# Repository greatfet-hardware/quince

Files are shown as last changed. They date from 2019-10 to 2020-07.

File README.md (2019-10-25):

# Quince
a 2.4 GHz SDR neighbor for GreatFET using 1-bit ADCs

Quince is a GreatFET neighbor that serves as a Software Defined Radio (SDR) receiver for the 2.4 GHz band using a 1-bit sampling technique.  It is intended specifically to enable all-channel Bluetooth monitoring, but it should support additional uses.

Quince features the TLV3502 dual comparator and an RF section based on the AD8347 quadrature demodulator.  Synthesis of a 2.4 GHz Local Oscillator (LO) is provided by ADF4360-0.  The 1-bit quadrature signals are sampled at 80+ Msps by the SGPIO peripheral on [Azalea](https://github.com/greatfet-hardware/azalea).

Channelization and demodulation are done in software on the host computer, but it may be necessary to add an FPGA to Quince in order to achieve real-time simultaneous monitoring of all Bluetooth channels.  The host software will likely be a rewrite of [gr-bluetooth](https://github.com/greatscottgadgets/gr-bluetooth) using [libbtbb](https://github.com/greatscottgadgets/libbtbb) (the core of software for [Ubertooth](https://greatscottgadgets.com/ubertoothone/)).

## Project Status

The first hardware prototype that achieves proof-of-concept has been assembled.  Software work is required before determining what changes are needed in the next hardware revision.

## Viewing or Modifying the Design

Required KiCad dependency:

https://github.com/greatscottgadgets/gsg-kicad-lib

If you are using git, the preferred way to install gsg-kicad-lib is to use the
submodule:

```
git submodule init && git submodule update
```

## Hardware Development Notes

Lower cost comparators that may have sufficient bandwidth:
* TLV3202, comparator, $0.60
* NCS2250, single, $0.20

It might be more cost-effective to use a wireless transmitter or transceiver IC to generate the LO, such as:
* CC2500
* ADF7242 (used on [Lucky Bamboo](https://github.com/greatfet-hardware/luckybamboo))

As an alternative to the comparators (and possibly to the quadrature demodulator as well) we may investigate the use of LVDS input on an FPGA.  This would be the preferred solution if an FPGA ends up on the board anyway for channelization.

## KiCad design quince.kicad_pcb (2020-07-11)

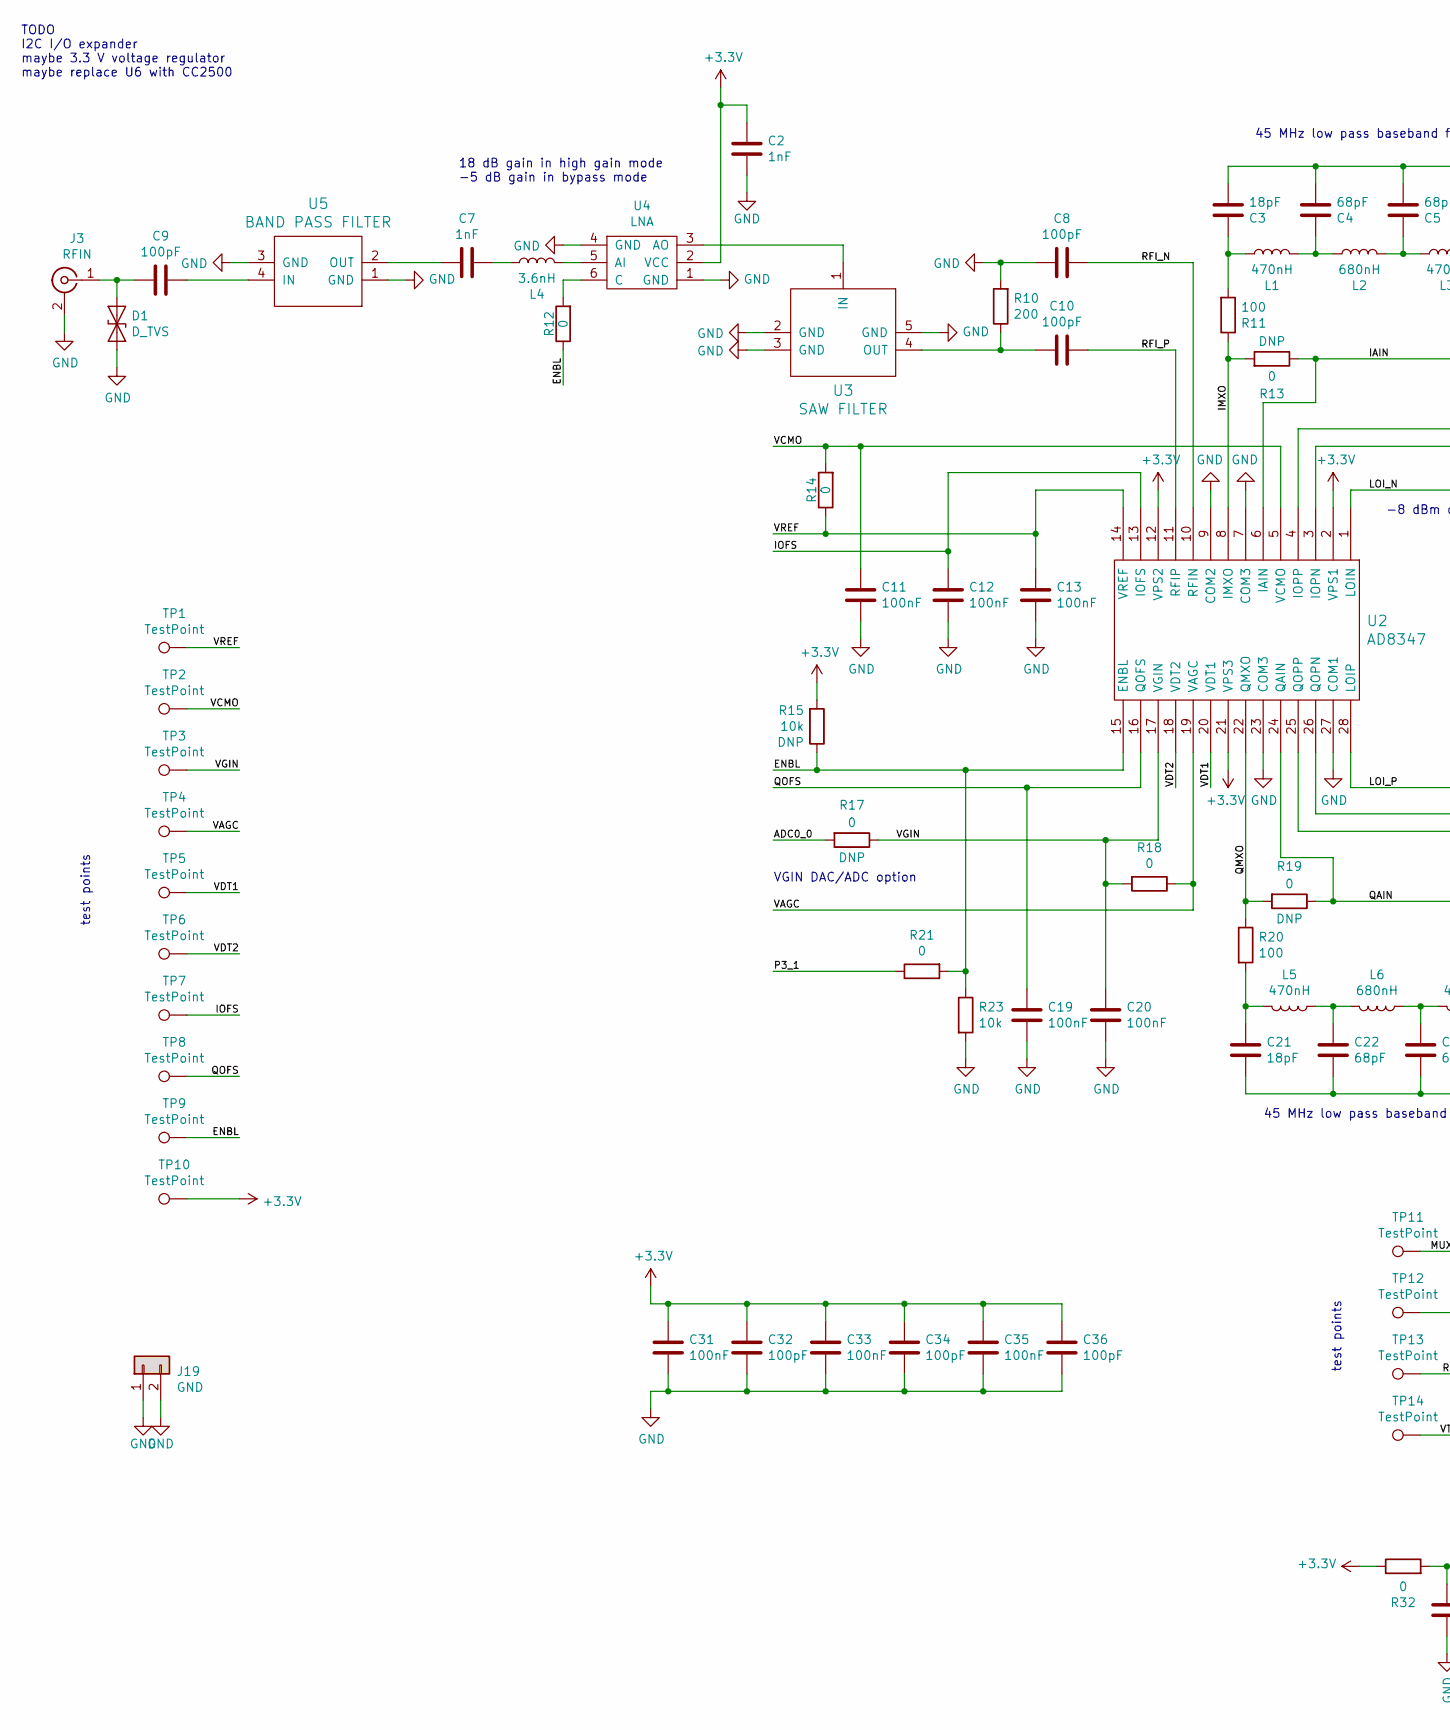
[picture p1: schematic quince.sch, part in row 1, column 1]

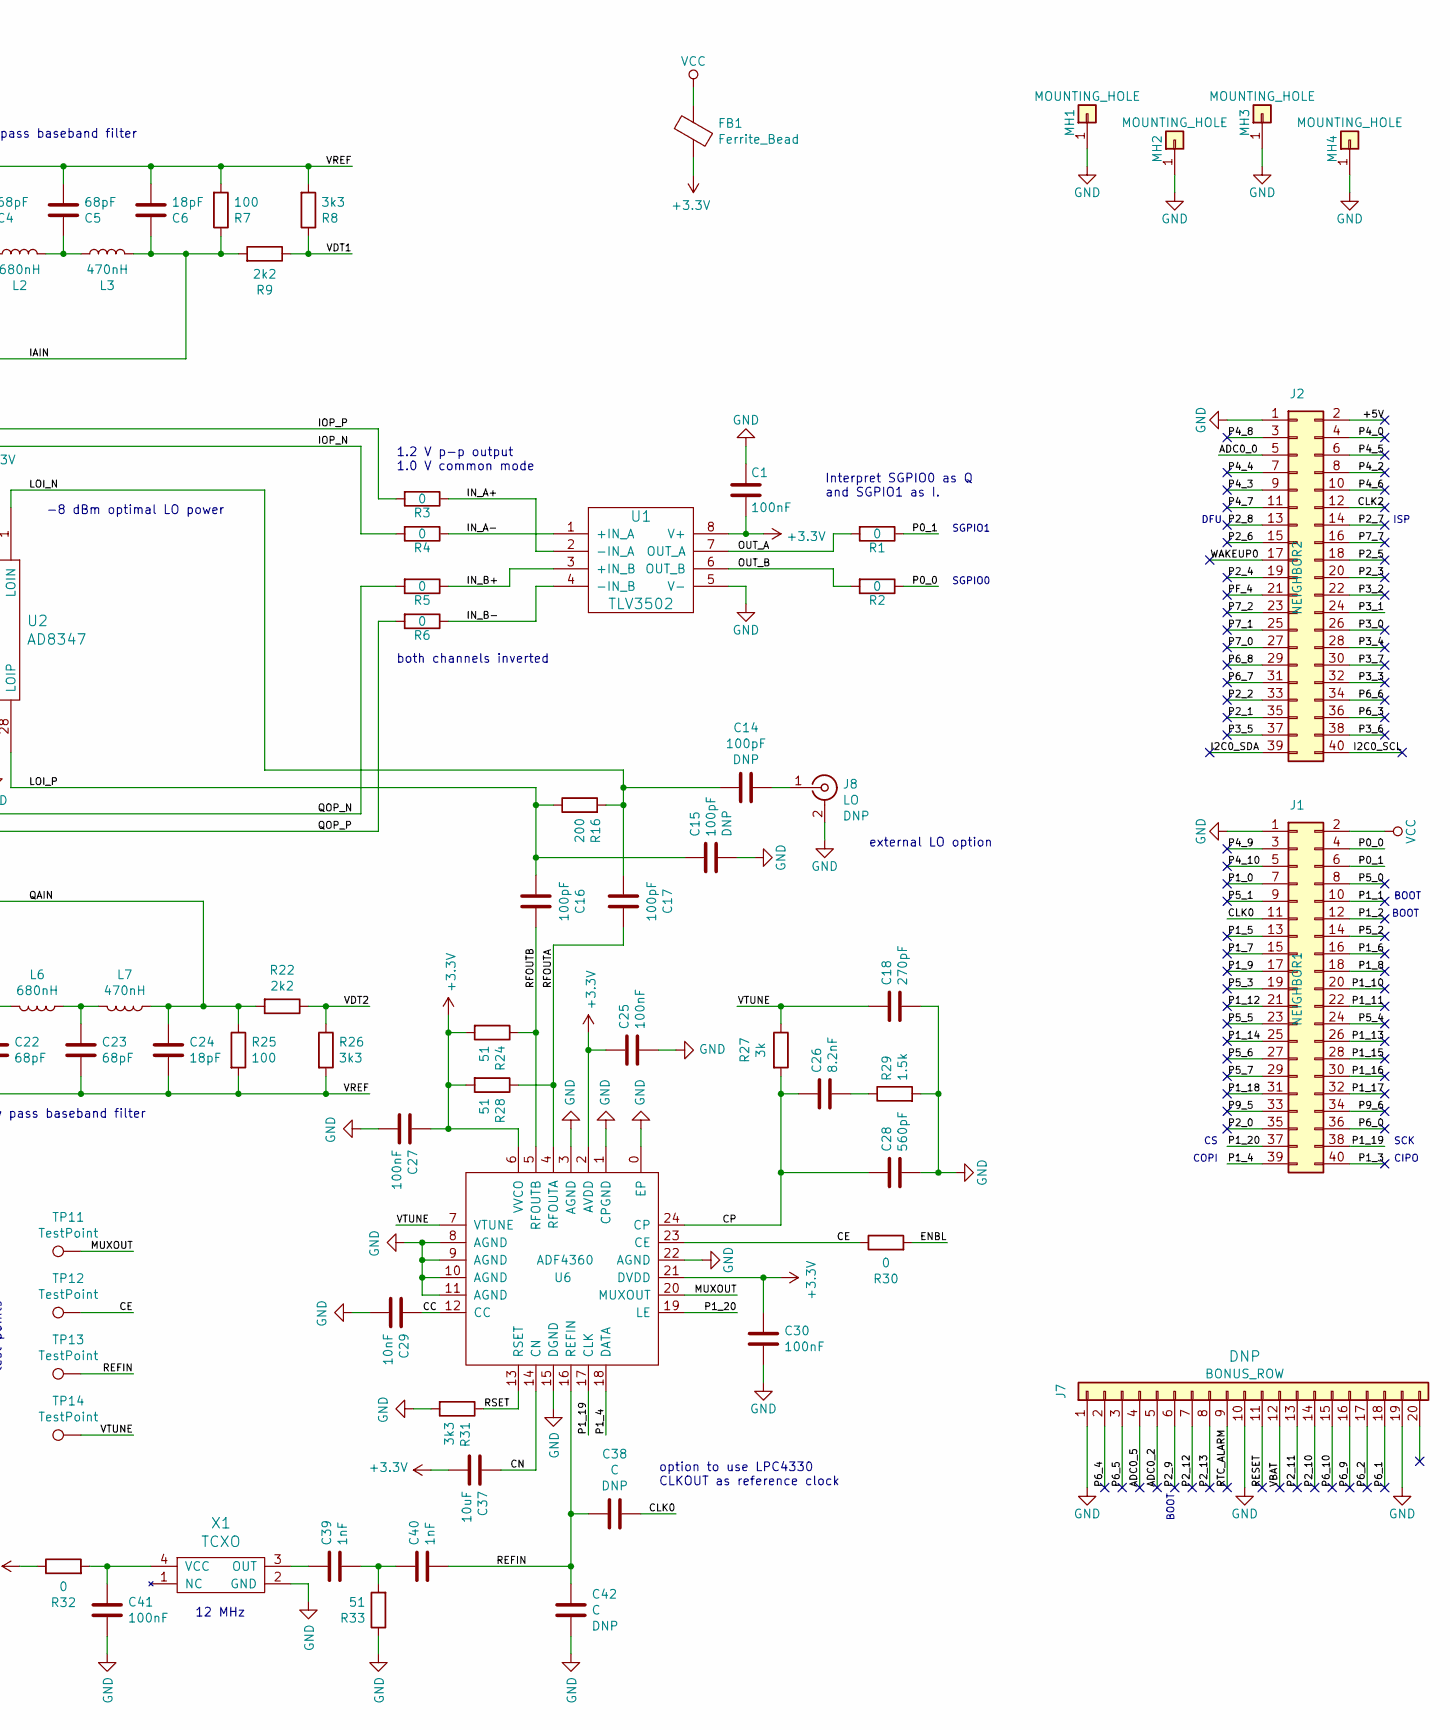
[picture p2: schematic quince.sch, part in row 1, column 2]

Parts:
C1, C11, C12, C13, C19, C20, C25, C27, C30, C31, C33, C35, C41: 100nF; 0402; Part Number CL05A104MP5NNNC
C2, C7, C39, C40: 1nF; 0402; Part Number UMK105B7102KV-F
C3, C6, C21, C24: 18pF; 0402; Part Number CC0402JRNPO9BN180
C4, C5, C22, C23: 68pF; 0402; Part Number CL05C680JB5NNNC
C8, C9, C10, C14, C15, C16, C17, C32, C34, C36: 100pF; 0402; Part Number CL05C101JB5NNNC
C18: 270pF; 0402; Part Number CL05B271KB5NNNC
C26: 8.2nF; 0402; Part Number CC0402KRX7R7BB822
C28: 560pF; 0402; Part Number CL05B561KB5NNNC
C29: 10nF; 0402; Part Number CL05B103KB5NNNC
C37: 10uF; 0805; Part Number CL21A106KPFNNNG
C38, C42: C; 0402
D1: D_TVS; 0402; Part Number LXES15AAA1-153
FB1: Ferrite_Bead; 0805; Part Number BLM21PG221SN1D
J1: NEIGHBOR1; HEADER-2x20; Part Number SSQ-120-23-G-D
J2: NEIGHBOR2; HEADER-2x20; Part Number SSQ-120-23-G-D
J3: RFIN; SMA-EDGE; Part Number CONREVSMA003.062
J7: BONUS_ROW; HEADER-1x20; Part Number SSQ-120-23-G-S
J8: LO; SMA-VERTICAL; Part Number 5-1814832-1
J19: GND; HEADER-1x2
L1, L3, L5, L7: 470nH; 0402; Part Number LK1005R47K-TV
L2, L6: 680nH; 0402; Part Number LK1005R68K-TV
L4: 3.6nH; 0402; Part Number HK10053N6S-T
MH1, MH2, MH3, MH4: MOUNTING_HOLE; HOLE126MIL-COPPER
R1, R2, R3, R4, R5, R6, R12, R13, R14, R17, R18, R19, R21, R30, R32: 0; 0402; Part Number RC0402JR-070RL
R7, R11, R20, R25: 100; 0402; Part Number RC0402JR-07100RL
R8, R26, R31: 3k3; 0402; Part Number RC0402JR-073K3L
R9, R22: 2k2; 0402; Part Number RC0402JR-072K2L
R10, R16: 200; 0402; Part Number RC0402JR-07200RL
R15, R23: 10k; 0402; Part Number RC0402JR-0710KL
R24, R28, R33: 51; 0402; Part Number RC0402JR-0751RL
R27: 3k; 0402; Part Number RC0402JR-073KL
R29: 1.5k; 0402; Part Number RC0402JR-071K5L
TP1, TP2, TP3, TP4, TP5, TP6, TP7, TP8, TP9, TP10, TP11, TP12, TP13, TP14: TestPoint; TESTPOINT-50MIL
U1: TLV3502; SOIC8-154; Part Number TLV3502AIDR
U2: AD8347; TSSOP28; Part Number AD8347ARUZ-REEL7
U3: SAW FILTER; B9413; Part Number B39242B9413K610
U4: LNA; BGA7H1N6; Part Number BGA5H1BN6E6327XTSA1
U5: BAND PASS FILTER; 2450BP39D100C; Part Number 2450BP39D100CE
U6: ADF4360; QFN24-4; Part Number ADF4360-0BCPZ
X1: TCXO; XTAL5.0x3.2mm; Part Number FT5HNBPK12.0-T1

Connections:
+3V3: C1.2, C2.2, C25.1, C27.1, C30.1, C31.1, C32.2, C33.1, C34.2, C35.1, C36.2, C37.2, FB1.2, R15.2, R24.2, R28.2, R32.1, TP10.1, U1.8 (V+), U2.2 (VPS1), U2.12 (VPS2), U2.21 (VPS3), U4.2 (VCC), U6.2 (AVDD), U6.6 (VVCO), U6.21 (DVDD)
/+5V: J2.2
/ADC0_0: J2.5, R17.2
/ADC0_2: J7.5
/ADC0_5: J7.4
/CC: C29.1, U6.12 (CC)
/CE: R30.1, TP12.1, U6.23 (CE)
/CLK0: C38.2, J1.11
/CLK2: J2.12
/CN: C37.1, U6.14 (CN)
/CP: C26.2, C28.2, R27.2, U6.24 (CP)
/ENBL: R12.1, R15.1, R21.2, R23.1, R30.2, TP9.1, U2.15 (ENBL)
/I2C0_SCL: J2.40
/I2C0_SDA: J2.39
/IAIN: C6.1, L3.1, R7.1, R9.2, R13.1, U2.6 (IAIN)
/IMXO: R11.1, R13.2, U2.8 (IMXO)
/IN_A+: R3.1, U1.2 (-IN_A)
/IN_A-: R4.1, U1.1 (+IN_A)
/IN_B+: R5.1, U1.3 (+IN_B)
/IN_B-: R6.1, U1.4 (-IN_B)
/IOFS: C12.1, TP7.1, U2.13 (IOFS)
/IOP_N: R4.2, U2.3 (IOPN)
/IOP_P: R3.2, U2.4 (IOPP)
/LOI_N: C14.2, C17.2, R16.2, U2.1 (LOIN)
/LOI_P: C15.2, C16.2, R16.1, U2.28 (LOIP)
/MUXOUT: TP11.1, U6.20 (MUXOUT)
/OUT_A: R1.2, U1.7 (OUT_A)
/OUT_B: R2.2, U1.6 (OUT_B)
/P0_0: J1.4, R2.1
/P0_1: J1.6, R1.1
/P1_0: J1.7
/P1_1: J1.10
/P1_2: J1.12
/P1_3: J1.40
/P1_4: J1.39, U6.18 (DATA)
/P1_5: J1.13
/P1_6: J1.16
/P1_7: J1.15
/P1_8: J1.18
/P1_9: J1.17
/P1_10: J1.20
/P1_11: J1.22
/P1_12: J1.21
/P1_13: J1.26
/P1_14: J1.25
/P1_15: J1.28
/P1_16: J1.30
/P1_17: J1.32
/P1_18: J1.31
/P1_19: J1.38, U6.17 (CLK)
/P1_20: J1.37, U6.19 (LE)
/P2_0: J1.35
/P2_1: J2.35
/P2_2: J2.33
/P2_3: J2.20
/P2_4: J2.19
/P2_5: J2.18
/P2_6: J2.15
/P2_7: J2.14
/P2_8: J2.13
/P2_9: J7.6
/P2_10: J7.14
/P2_11: J7.13
/P2_12: J7.7
/P2_13: J7.8
/P3_0: J2.26
/P3_1: J2.24, R21.1
/P3_2: J2.22
/P3_3: J2.32
/P3_4: J2.28
/P3_5: J2.37
/P3_6: J2.38
/P3_7: J2.30
/P4_0: J2.4
/P4_2: J2.8
/P4_3: J2.9
/P4_4: J2.7
/P4_5: J2.6
/P4_6: J2.10
/P4_7: J2.11
/P4_8: J2.3
/P4_9: J1.3
/P4_10: J1.5
/P5_0: J1.8
/P5_1: J1.9
/P5_2: J1.14
/P5_3: J1.19
/P5_4: J1.24
/P5_5: J1.23
/P5_6: J1.27
/P5_7: J1.29
/P6_0: J1.36
/P6_1: J7.18
/P6_2: J7.17
/P6_3: J2.36
/P6_4: J7.2
/P6_5: J7.3
/P6_6: J2.34
/P6_7: J2.31
/P6_8: J2.29
/P6_9: J7.16
/P6_10: J7.15
/P7_0: J2.27
/P7_1: J2.25
/P7_2: J2.23
/P7_7: J2.16
/P9_5: J1.33
/P9_6: J1.34
/PF_4: J2.21
/QAIN: C24.1, L7.1, R19.1, R22.2, R25.1, U2.24 (QAIN)
/QMXO: R19.2, R20.1, U2.22 (QMXO)
/QOFS: C19.1, TP8.1, U2.16 (QOFS)
/QOP_N: R5.2, U2.26 (QOPN)
/QOP_P: R6.2, U2.25 (QOPP)
/REFIN: C38.1, C40.2, C42.2, TP13.1, U6.16 (REFIN)
/RESET: J7.11
/RFI_N: C8.1, U2.10 (RFIN)
/RFI_P: C10.1, U2.11 (RFIP)
/RFOUTA: C17.1, R28.1, U6.4 (RFOUTA)
/RFOUTB: C16.1, R24.1, U6.5 (RFOUTB)
/RSET: R31.1, U6.13 (RSET)
/RTC_ALARM: J7.9
/VAGC: R18.1, TP4.1, U2.19 (VAGC)
/VBAT: J7.12
/VCMO: C11.1, R14.2, TP2.1, U2.5 (VCMO)
/VDT1: R8.1, R9.1, TP5.1, U2.20 (VDT1)
/VDT2: R22.1, R26.1, TP6.1, U2.18 (VDT2)
/VGIN: C20.1, R17.1, R18.2, TP3.1, U2.17 (VGIN)
/VREF: C3.2, C4.2, C5.2, C6.2, C13.1, C21.2, C22.2, C23.2, C24.2, R7.2, R8.2, R14.1, R25.2, R26.2, TP1.1, U2.14 (VREF)
/VTUNE: C18.2, R27.1, TP14.1, U6.7 (VTUNE)
/WAKEUP0: J2.17
GND: C1.1, C2.1, C8.2, C11.2, C12.2, C13.2, C15.1, C18.1, C19.2, C20.2, C25.2, C27.2, C28.1, C29.2, C30.2, C31.2, C32.1, C33.2, C34.1, C35.2, C36.1, C41.2, C42.1, D1.2 (A2), J1.1, J2.1, J3.2 (Ext), J7.1, J7.10, J7.19, J8.2 (Ext), J19.1, J19.2, MH1.1, MH2.1, MH3.1, MH4.1, R10.2, R23.2, R29.2, R31.2, R33.1, U1.5 (V-), U2.7 (COM3), U2.9 (COM2), U2.23 (COM3), U2.27 (COM1), U3.2 (GND), U3.3 (GND), U3.5 (GND), U4.1 (GND), U4.4 (GND), U5.1 (GND), U5.3 (GND), U6.0 (EP), U6.1 (CPGND), U6.3 (AGND), U6.8 (AGND), U6.9 (AGND), U6.10 (AGND), U6.11 (AGND), U6.15 (DGND), U6.22 (AGND), X1.2 (GND)
unnamed: C3.1, L1.2, R11.2
unnamed: C4.1, L1.1, L2.2
unnamed: C5.1, L2.1, L3.2
unnamed: C7.1, U5.2 (OUT)
unnamed: C7.2, L4.2
unnamed: C9.1, U5.4 (IN)
unnamed: C9.2, D1.1 (A1), J3.1 (In)
unnamed: C10.2, R10.1, U3.4 (OUT)
unnamed: C14.1, J8.1 (In)
unnamed: C21.1, L5.2, R20.2
unnamed: C22.1, L5.1, L6.2
unnamed: C23.1, L6.1, L7.2
unnamed: C26.1, R29.1
unnamed: C39.1, X1.3 (OUT)
unnamed: C39.2, C40.1, R33.2
unnamed: C41.1, R32.2, X1.4 (VCC)
unnamed: L4.1, U4.5 (AI)
unnamed: R12.2, U4.6 (C)
unnamed: U3.1 (IN), U4.3 (AO)
VCC: FB1.1, J1.2

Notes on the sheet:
CIPO
COPI
SCK
ISP
DFU
BOOT
SGPIO0
SGPIO1
45 MHz low pass baseband filter
both channels inverted
1.2 V p-p output 1.0 V common mode
external LO option
-8 dBm optimal LO power
test points
VGIN DAC/ADC option
Interpret SGPIO0 as Q and SGPIO1 as I.
18 dB gain in high gain mode -5 dB gain in bypass mode
TODO I2C I/O expander maybe 3.3 V voltage regulator maybe replace U6 with CC2500
option to use LPC4330 CLKOUT as reference clock
12 MHz

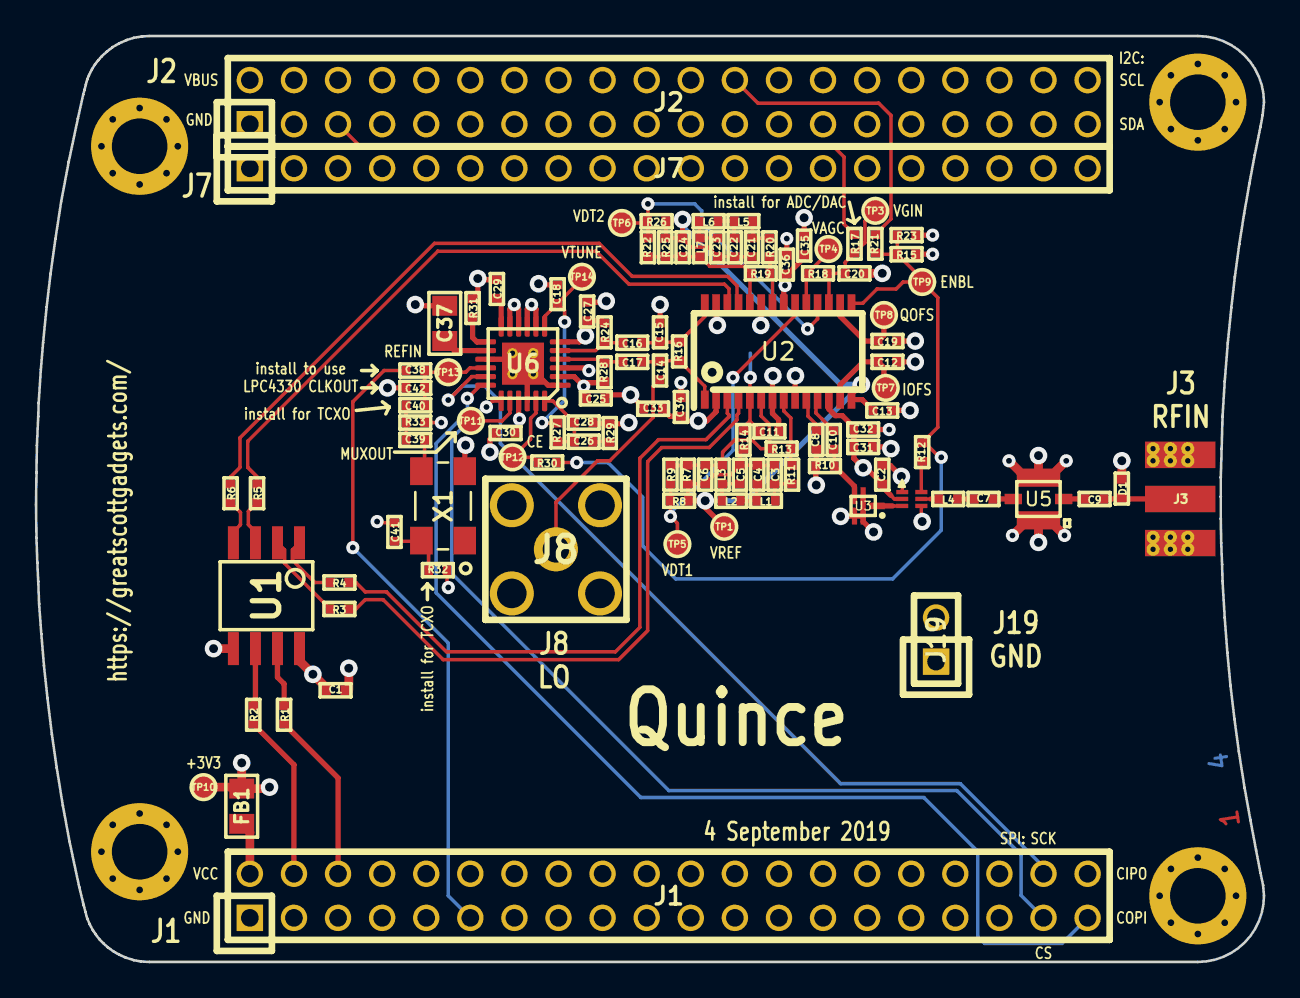
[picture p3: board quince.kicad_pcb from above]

Board: 4 copper layers, 70.7 x 53.3 mm, 115 parts (1 on the bottom side), 67 nets.

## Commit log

2019-05-27 split quince into separate repository
    [azalea.kicad_pcb, azalea.sch, begonia.kicad_pcb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]
2019-08-31 updated to KiCad 5.1
    [quince.sch]
2019-09-01 add RF section to schematic copied from Daisho/rx2400ism
    [quince.sch]
2019-09-01 add sym-lib-table, update .gitignore for KiCad 5.1
2019-09-01 add frequency synthesizer
    [quince.sch]
2019-09-02 change U4 LNA from MAX2641 to BGA5H1BN6 to reduce cost and part count
    [quince.sch]
2019-09-03 assign footprints
    [quince.kicad_pcb, quince.sch]
2019-09-04 complete layout
    [quince.kicad_pcb, quince.sch]
2019-09-04 use proper test point symbols
    [quince.kicad_pcb, quince.sch]
2019-09-04 assign less confusing names to inner copper layers
    [quince.kicad_pcb]
2019-09-23 select parts
    [quince.kicad_pcb, quince.sch]
2019-10-02 fix U1 part selection
    [quince.sch]
2020-07-03 adopt OSHWA convention for SPI signal names https://www.oshwa.org/a-resolution-to-redefine-spi-signal-names
    [quince.kicad_pcb, quince.sch]

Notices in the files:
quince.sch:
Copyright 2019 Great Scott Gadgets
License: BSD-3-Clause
